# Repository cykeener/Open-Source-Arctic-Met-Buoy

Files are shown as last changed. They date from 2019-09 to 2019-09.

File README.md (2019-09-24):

# Open-Source-Arctic-Met-Buoy
General info, PCB design files, and hull / enclosure design files to build a meteorological (met) buoy to collect GPS location, external temperature, and atmospheric pressure in a cold weather environment.  This version of the buoy was designed in the fall of 2018, and deployed in the winter of 2019.

The intent of this repository is to maintain general info, PCB design files (from Eagle), 3D printable stl files (from Fusion 360), and a series of BOMs that will allow the user to build an open source met buoy that runs on Arduino code maintained by tgidave https://github.com/tgidave/icedrifter

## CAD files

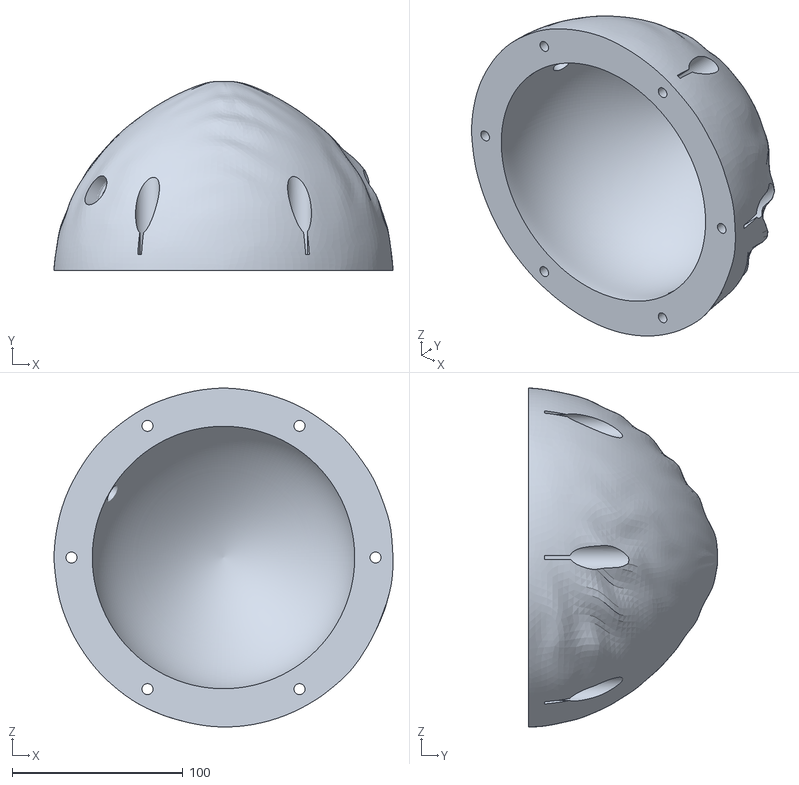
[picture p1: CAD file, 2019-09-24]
icedrift_hardcase_top.stl
198.5 x 110.9 x 198.4

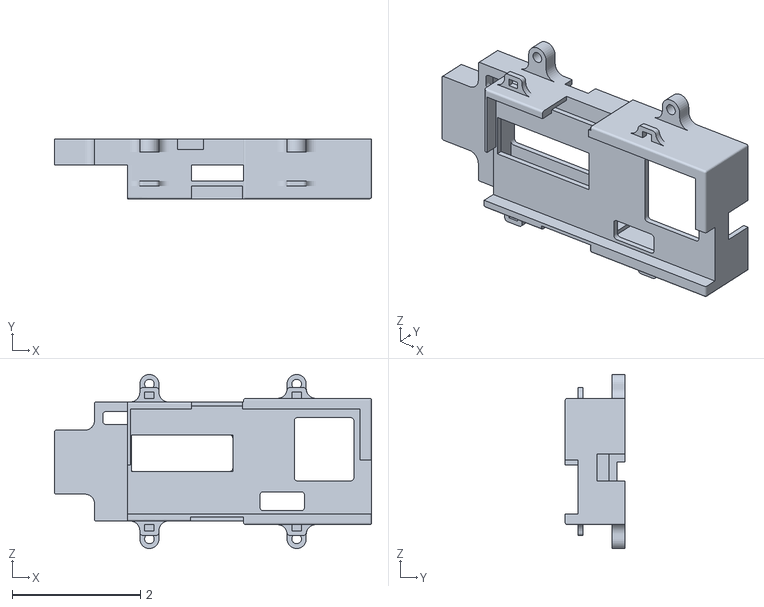
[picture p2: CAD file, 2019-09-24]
icedrift_PCB_tray.stl
4.95 x 0.93 x 2.72

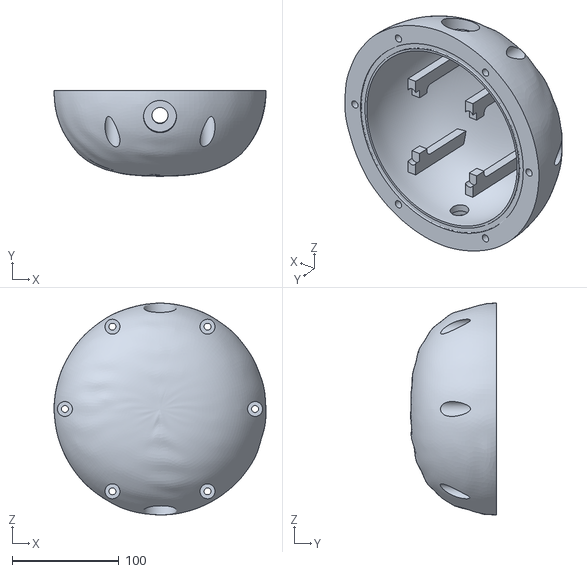
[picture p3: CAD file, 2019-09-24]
icedrift_hardcase_bottom.stl
198.5 x 80.4 x 198.4

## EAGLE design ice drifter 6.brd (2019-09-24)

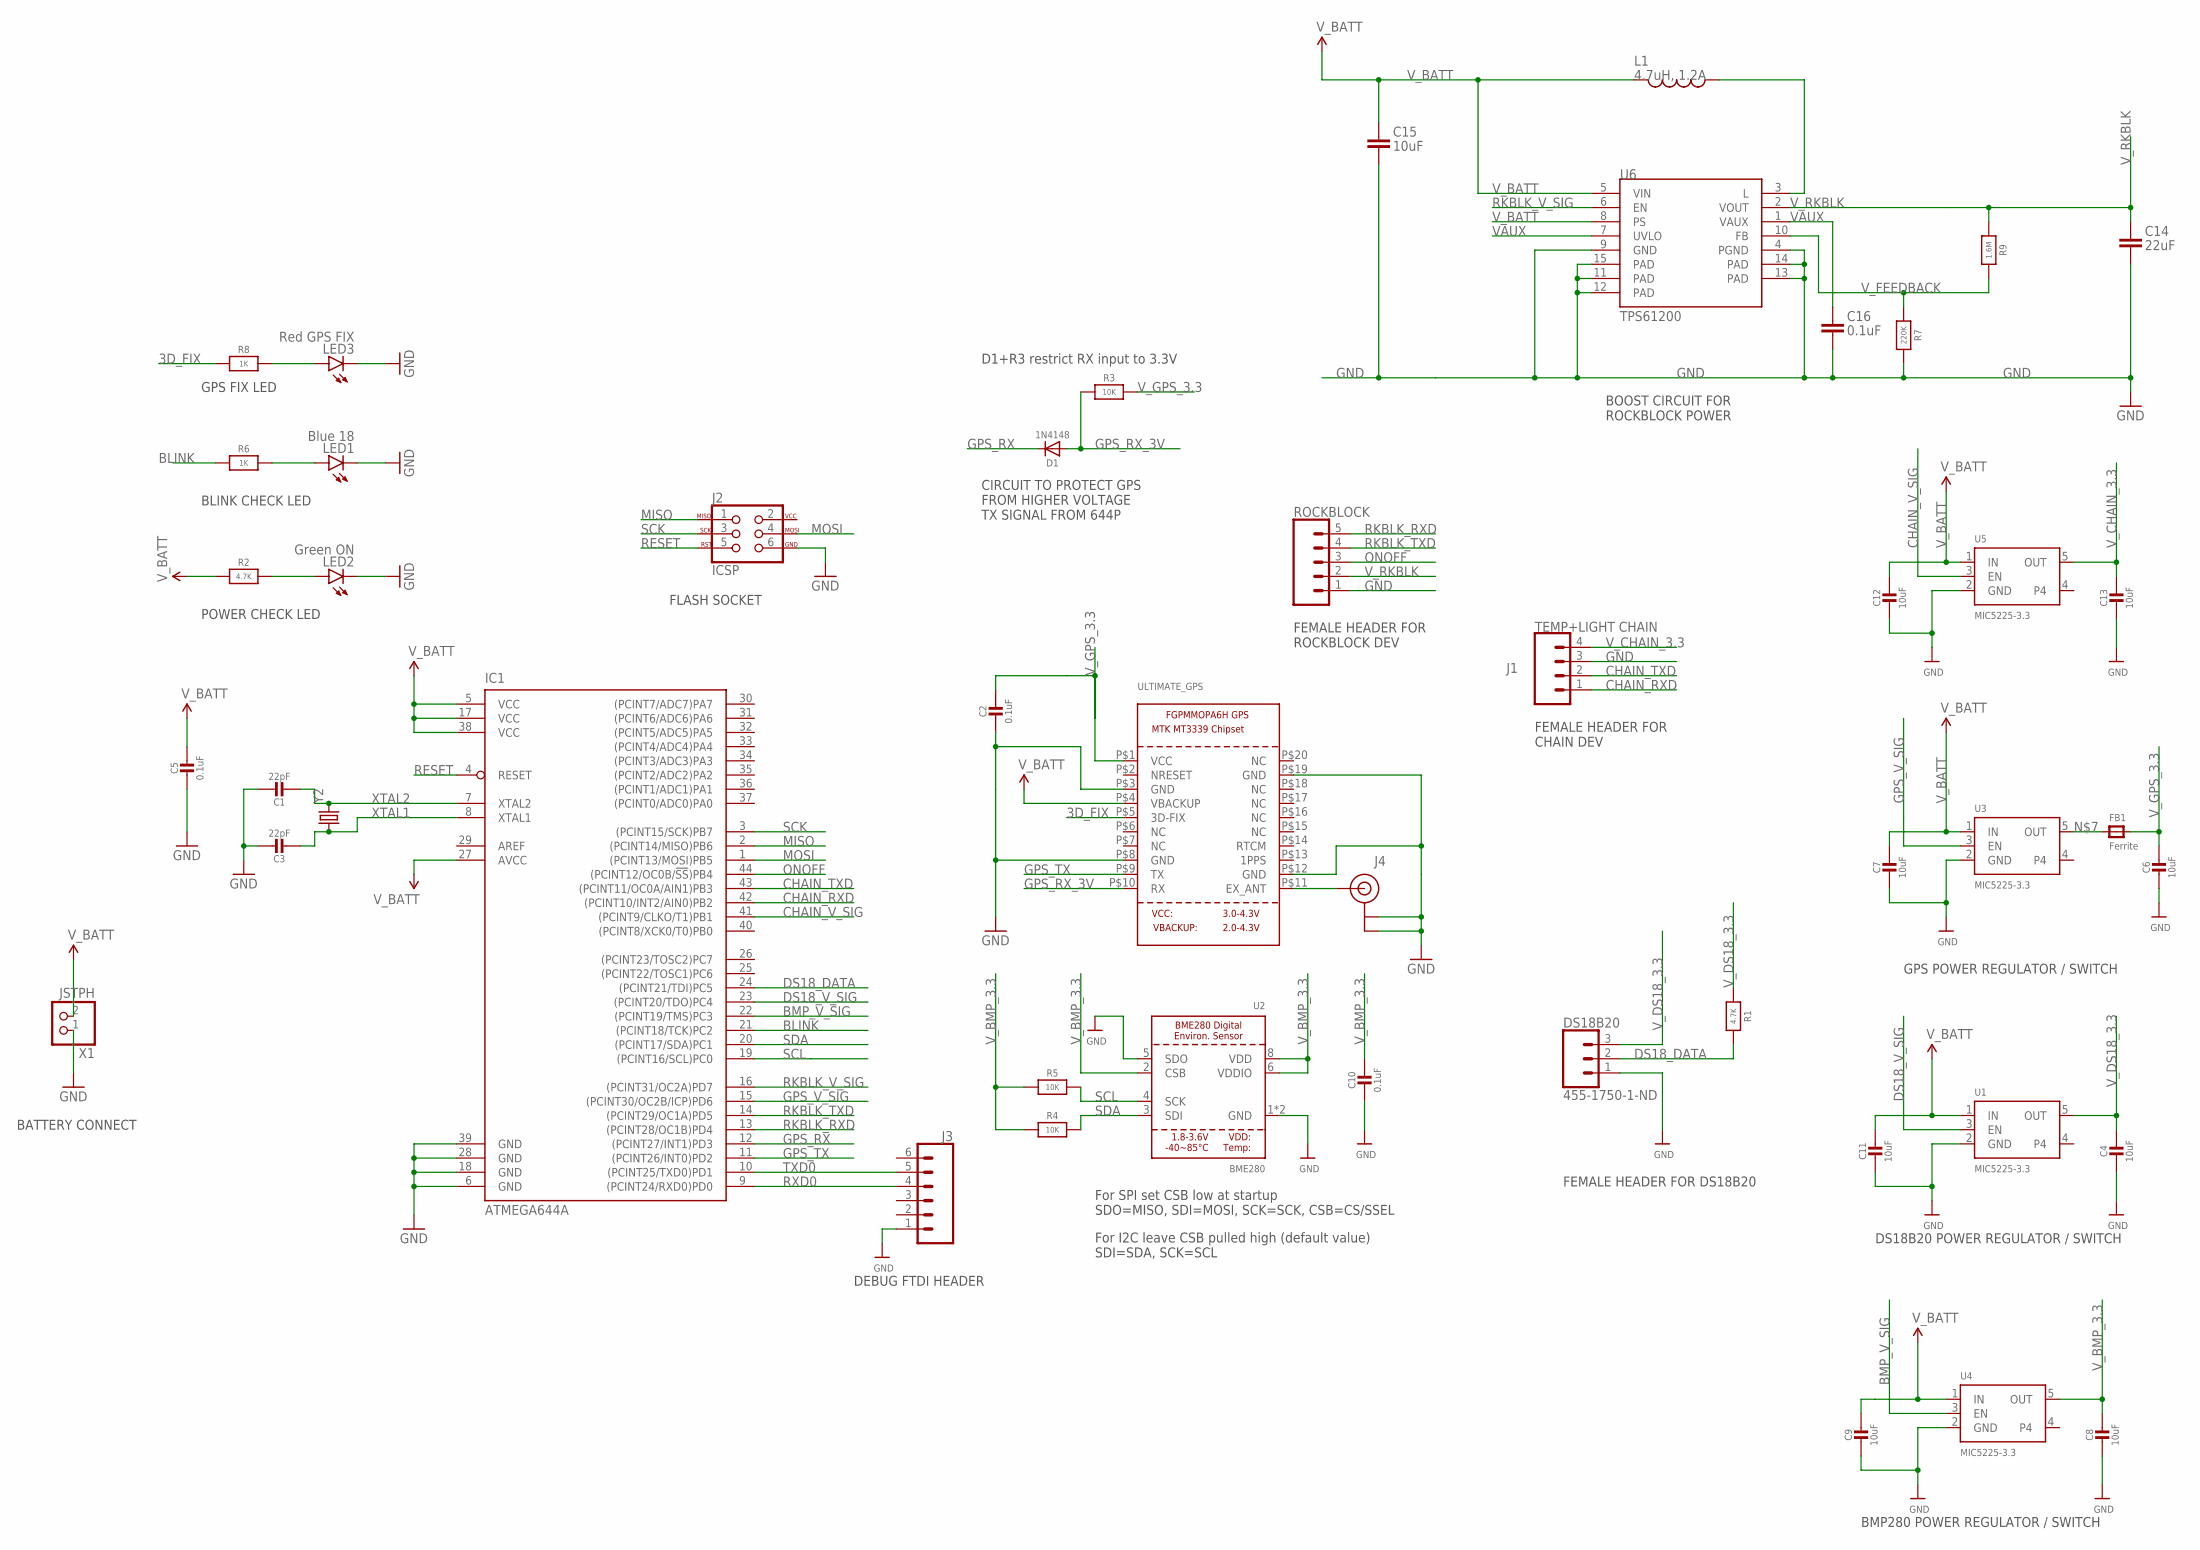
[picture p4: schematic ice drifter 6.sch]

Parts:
C1, C3: 22pF; 0805-NO@2
C2, C5, C10: 0.1uF; 0805-NO@2
C4, C6, C7, C8, C9, C11, C12, C13: 10uF; 0805-NO@2
C14: 22uF; 0805
C15: 10uF; 1206
C16: 0.1uF; 0805
D1: 1N4148; SOD-323
DS18B20: 455-1750-1-ND; 1X03
FB1: Ferrite; 0805-NO@1
IC1: ATMEGA644A; TQFP44
J1: TEMP+LIGHT CHAIN; 1X04
J2: ICSP; 2X3-NS
J3: CONN_06SILK_FEMALE_PTH; 1X06
J4: U.FL
L1: 4.7uH, 1.2A; CDRH2D09
LED1: Blue 18; LED-1206
LED2: Green ON; LED-1206
LED3: Red GPS FIX; LED-1206
R1, R2: 4.7K; 0805-NO
R3, R4, R5: 10K; 0805-NO
R6, R8: 1K; 0805-NO
R7: 220K; 0805-NO
R9: 1.6M; 0805-NO
ROCKBLOCK: CONN_05; 1X05
U1, U3, U4, U5: MIC5225-3.3; SOT23-5
U2: BME280
U6: TPS61200; QFN-10_PAD
ULTIMATE_GPS: GPS_FGPMMOPA6H; FGPMMOPA6H
X1: JSTPH; JSTPH2
Y2: CRYSTALTXC-7A; CRYSTAL-TXC-7A

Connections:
3D_FIX: R8.1, ULTIMATE_GPS.P$5 (3D-FIX)
BLINK: IC1.21 ((PCINT18/TCK)PC2), R6.1
BMP_V_SIG: IC1.22 ((PCINT19/TMS)PC3), U4.3 (EN)
CHAIN_RXD: IC1.42 ((PCINT10/INT2/AIN0)PB2), J1.1
CHAIN_TXD: IC1.43 ((PCINT11/OC0A/AIN1)PB3), J1.2
CHAIN_V_SIG: IC1.41 ((PCINT9/CLKO/T1)PB1), U5.3 (EN)
COIL: L1.P$1 (1), U6.3 (L)
DS18_DATA: DS18B20.2, IC1.24 ((PCINT21/TDI)PC5), R1.2
DS18_V_SIG: IC1.23 ((PCINT20/TDO)PC4), U1.3 (EN)
GND: C1.1, C2.2, C3.1, C4.2, C5.2, C6.2, C7.2, C8.2, C9.2, C10.2, C11.2, C12.2, C13.2, C14.2, C15.2, C16.2, DS18B20.1, IC1.6 (GND), IC1.18 (GND), IC1.28 (GND), IC1.39 (GND), J1.3, J2.6, J3.1, J4.1 (GND), J4.2 (GND), LED1.C, LED2.C, LED3.C, R7.2, ROCKBLOCK.1, U1.2 (GND), U2.1 (GND), U2.5 (SDO), U2.7 (GND), U3.2 (GND), U4.2 (GND), U5.2 (GND), U6.4 (PGND), U6.9 (GND), U6.11 (PAD), U6.12 (PAD), U6.13 (PAD), U6.14 (PAD), U6.15 (PAD), ULTIMATE_GPS.P$3 (GND), ULTIMATE_GPS.P$8 (GND), ULTIMATE_GPS.P$12 (GND), ULTIMATE_GPS.P$19 (GND), X1.1
GPS_RX: D1.C, IC1.12 ((PCINT27/INT1)PD3)
GPS_RX_3V: D1.A, R3.1, ULTIMATE_GPS.P$10 (RX)
GPS_TX: IC1.11 ((PCINT26/INT0)PD2), ULTIMATE_GPS.P$9 (TX)
GPS_V_SIG: IC1.15 ((PCINT30/OC2B/ICP)PD6), U3.3 (EN)
MISO: IC1.2 ((PCINT14/MISO)PB6), J2.1
MOSI: IC1.1 ((PCINT13/MOSI)PB5), J2.4
unnamed: LED2.A, R2.2
unnamed: LED1.A, R6.2
unnamed: LED3.A, R8.2
unnamed: FB1.1, U3.5 (OUT)
ONOFF: IC1.44 ((PCINT12/OC0B/!SS!)PB4), ROCKBLOCK.3
RESET: IC1.4 (RESET), J2.5
RKBLK_RXD: IC1.13 ((PCINT28/OC1B)PD4), ROCKBLOCK.5
RKBLK_TXD: IC1.14 ((PCINT29/OC1A)PD5), ROCKBLOCK.4
RKBLK_V_SIG: IC1.16 ((PCINT31/OC2A)PD7), U6.6 (EN)
RXD0: IC1.9 ((PCINT24/RXD0)PD0), J3.4
SCK: IC1.3 ((PCINT15/SCK)PB7), J2.3
SCL: IC1.19 ((PCINT16/SCL)PC0), R5.2, U2.4 (SCK)
SDA: IC1.20 ((PCINT17/SDA)PC1), R4.2, U2.3 (SDI)
TXD0: IC1.10 ((PCINT25/TXD0)PD1), J3.5
U.FL_ANT: J4.FEED (SIGNAL), ULTIMATE_GPS.P$11 (EX_ANT)
VAUX: C16.1, U6.1 (VAUX), U6.7 (UVLO)
V_BATT: C5.1, C7.1, C9.1, C11.1, C12.1, C15.1, IC1.5 (VCC), IC1.17 (VCC), IC1.27 (AVCC), IC1.38 (VCC), L1.P$2 (2), R2.1, U1.1 (IN), U3.1 (IN), U4.1 (IN), U5.1 (IN), U6.5 (VIN), U6.8 (PS), ULTIMATE_GPS.P$4 (VBACKUP), X1.2
V_BMP_3.3: C8.1, C10.1, R4.1, R5.1, U2.2 (CSB), U2.6 (VDDIO), U2.8 (VDD), U4.5 (OUT)
V_CHAIN_3.3: C13.1, J1.4, U5.5 (OUT)
V_DS18_3.3: C4.1, DS18B20.3, R1.1, U1.5 (OUT)
V_FEEDBACK: R7.1, R9.2, U6.10 (FB)
V_GPS_3.3: C2.1, C6.1, FB1.2, R3.2, ULTIMATE_GPS.P$1 (VCC)
V_RKBLK: C14.1, R9.1, ROCKBLOCK.2, U6.2 (VOUT)
XTAL1: C3.2, IC1.8 (XTAL1), Y2.P$1 (1)
XTAL2: C1.2, IC1.7 (XTAL2), Y2.P$2 (2)

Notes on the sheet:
For SPI set CSB low at startup SDO=MISO, SDI=MOSI, SCK=SCK, CSB=CS/SSEL
For I2C leave CSB pulled high (default value) SDI=SDA, SCK=SCL
D1+R3 restrict RX input to 3.3V
GPS POWER REGULATOR / SWITCH
DS18B20 POWER REGULATOR / SWITCH
BMP280 POWER REGULATOR / SWITCH
FEMALE HEADER FOR DS18B20
DEBUG FTDI HEADER
FEMALE HEADER FOR ROCKBLOCK DEV
BOOST CIRCUIT FOR ROCKBLOCK POWER
CIRCUIT TO PROTECT GPS FROM HIGHER VOLTAGE TX SIGNAL FROM 644P
BATTERY CONNECT
POWER CHECK LED
BLINK CHECK LED
GPS FIX LED
FLASH SOCKET
FEMALE HEADER FOR CHAIN DEV

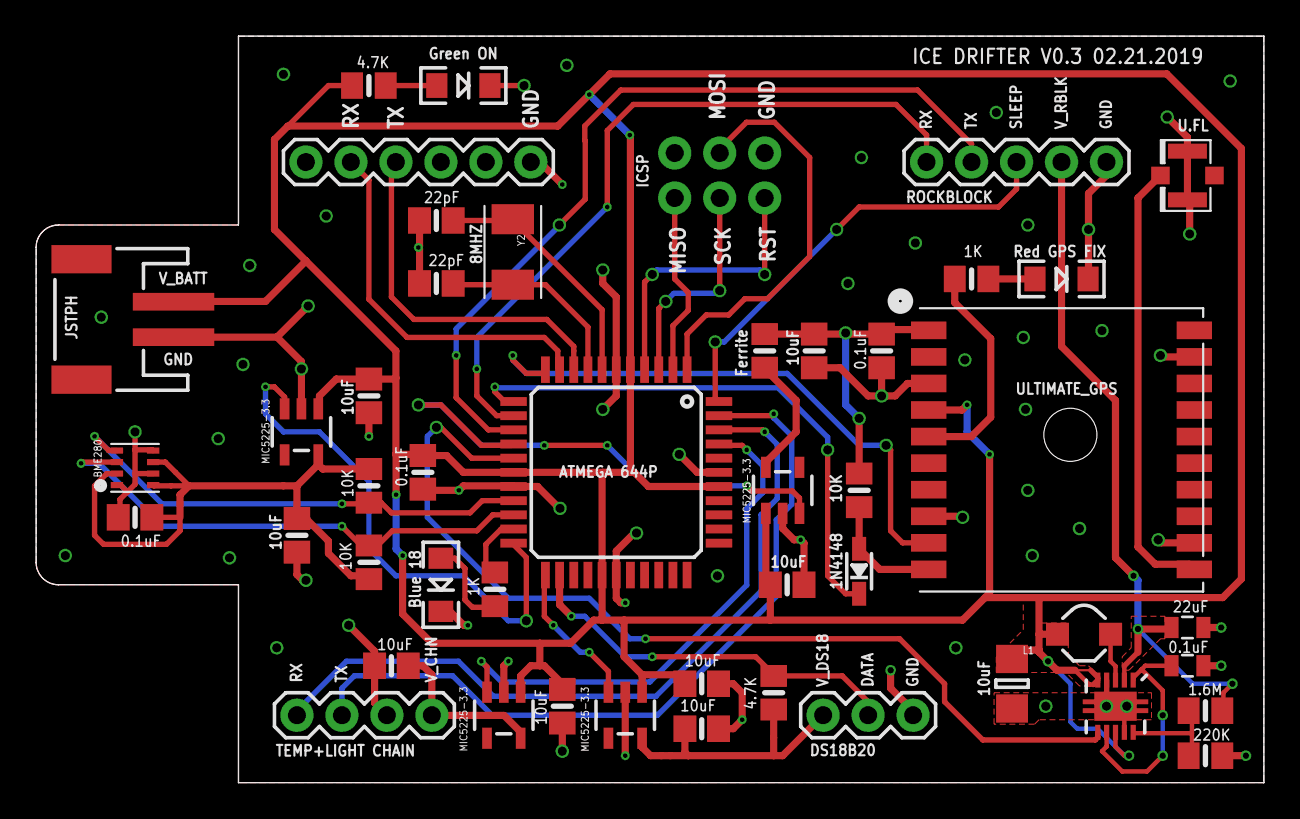
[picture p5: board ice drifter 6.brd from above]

Board: 2 copper layers, 69.3 x 42.2 mm, 47 parts (0 on the bottom side), 41 nets.

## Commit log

2019-09-24 PCB Version 6
    Use with Arduino code: https://github.com/tgidave/icedrifter
    [ice drifter 6.brd, ice drifter 6.sch]
2019-09-24 stl print files for the buoy hull
    There is a top file, bottom file, and PCB tray to fit Icedrifter 6 PCB, and a Rockblock 9602 modem. Look to the readme for info on fasteners and o-rings from McMaster-Carr.
    [icedrift_PCB_tray.stl, icedrift_hardcase_bottom.stl, icedrift_hardcase_top.stl]

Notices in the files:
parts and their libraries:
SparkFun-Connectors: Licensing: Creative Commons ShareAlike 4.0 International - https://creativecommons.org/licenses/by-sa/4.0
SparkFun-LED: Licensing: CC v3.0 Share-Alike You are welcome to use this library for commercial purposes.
